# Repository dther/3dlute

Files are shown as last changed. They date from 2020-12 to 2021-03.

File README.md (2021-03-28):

# 3D Lute Project

An attempt at making a cheap and accessible student lute that can be printed on a standard FDM 3D printer,
and be similar enough in tone and playing style to be useful for learning the fundamentals.

Various instruments of the Renaissance-Baroque lute family will hopefully become available.
Currently, only one instrument is being worked on.

## Current Instruments

 - Lutekulele *WIP* - A lute-shaped ukelele, strung in doubled courses and tuned g-c-e-a,
   with the G course in octaves and all others in unison.
   Tuned like a renaissance guitar, and thus already has a repetoire.
   Primarily a proof-of-concept that this project is at all possible.
   Could charitably be called a "mandore" or "mandolino", and restrung to have a more historical
   tuning of g-f-g-f or g-c-g-c.

## Planned instruments

 - Medieval Lute - An early medieval lute, 4 strings in double courses.
 - 6c Tenor Renaissance Lute - The goal of this project.
 - 12c Baroque Lute - Hopefully. I doubt this kind of thing is possible.

## LICENSE

(c) Rudy Dellomas III,
See github profile or <https://dther.xyz> for contact details

Published under [CC BY-SA-NC][#license].

This is primarily to prevent unscrupulous parties from printing and selling these
in large print farms. Please send me an email if you'd like to negotiate commercial usage,
or have produced a creative derivative and would like to relicense.

[#license]:https://creativecommons.org/licenses/by-nc-sa/4.0/

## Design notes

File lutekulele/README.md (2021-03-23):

# Lutekulele

WARNING: this is currently *Heavily in progress.*
I don't have a solid method of generating and tweaking stl files yet,
it's a lot of eyeballing and prayer right now.
Make at your own risk.

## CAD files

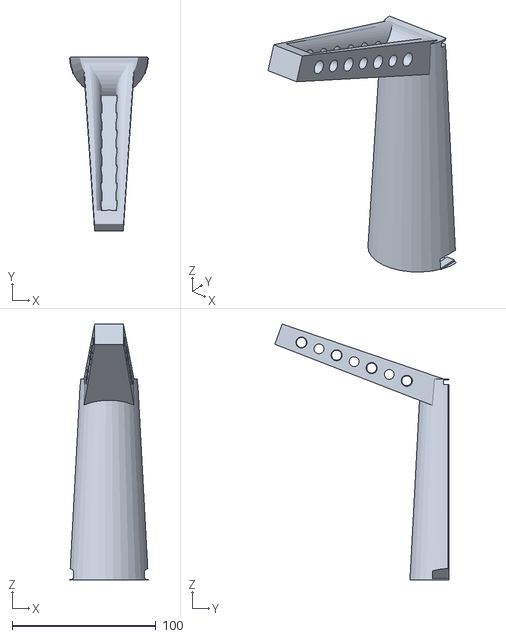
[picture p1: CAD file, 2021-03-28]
lutekulele/neck.stl
54.8 x 121.3 x 178.1

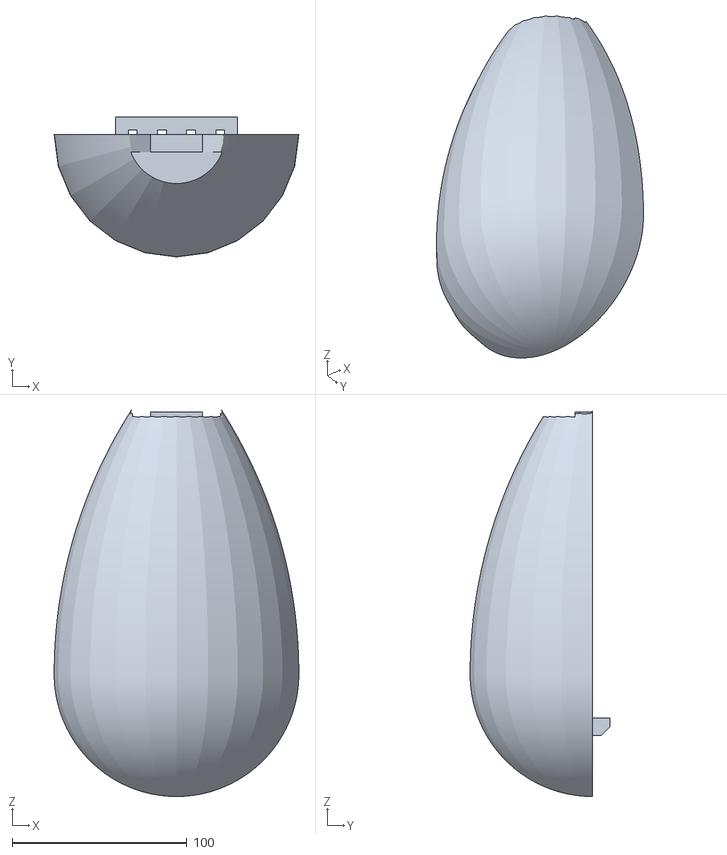
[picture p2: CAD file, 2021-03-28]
lutekulele/body.stl
140.0 x 80.0 x 220.8

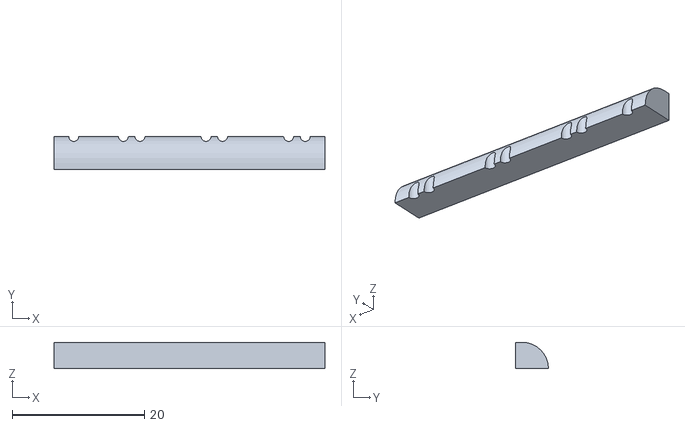
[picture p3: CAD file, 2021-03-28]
lutekulele/nut.stl
41.0 x 5.00 x 4.00

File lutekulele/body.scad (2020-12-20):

include <src/BOSL/shapes.scad>
include <src/BOSL/transforms.scad>
use <src/BOSL/constants.scad>
use <neck.scad>

//set to 0 so as to make hole bigger
neck_block_tolerance=0;

module luteshape(radius) {
    translate([0,radius,0]) union() {
        circle(radius);
        difference() {
            intersection() {
                translate([radius,0,0]) circle(2*radius);
                translate([-radius,0,0]) circle(2*radius);
            }
            translate([0,-radius,0]) square(radius*2, center=true);
        }
    }
}

module luteshape2(radius) {
    translate([0,radius,0]) union() {
        circle(radius);
        
        difference() {
        
            intersection() {
            
                translate([3*radius,0,0]) circle(4*radius);
                translate([-3*radius,0,0]) circle(4*radius);
            }
            translate([0,-2*radius,0]) square(radius*4, center=true);
        }
    }
}

module lutebody(radius) {
    rotate_extrude(angle=180, $fn=24) difference() {
        luteshape2(radius, $fn=360);
        square(radius*100);
    }
}

module roughneck() {
// used for visualisation purposes but also for
// cutting the slot in the neck block
    translate([0, 0, 210]) union() {
        //NUT
        translate([0,-4,140]) nut();
        difference() {
            neckbody(neck_block_tolerance=neck_block_tolerance);
            translate([0,-4,140]) nut_cut();
        }
        difference() {
            cyl(l=10, d1=56, d2=56, align=ALIGN_POS, $fn=360);
            // translate to account for fang inlay
            translate([0,-10,0]) cuboid(size=[100,100,20], align=V_BACK+V_UP);
            
        }
    }
}

module soundbar(l=65,thickness=3,height=10) {
    difference() {
        cuboid(size=[l, height, thickness], align=V_FRONT+V_UP+V_DOWN);
        //scallop
        translate([l/2,1,0]) cyl(d=height*4,h=thickness+2, align=V_FRONT+V_UP+V_DOWN);
        mirror([1,0,0]) translate([l/2,1,0]) cyl(d=height*4,h=thickness+2, align=V_FRONT+V_UP+V_DOWN);
    }
}

module bridge(length=70, course_width=5, string_height=5, bridge_height=10) {
    difference() {
        cuboid(size=[length,bridge_height,10], align=V_BACK+V_DOWN, chamfer=5,
                edges=EDGE_BOT_BK);
        //slots for strings
        hole_height=(bridge_height-string_height)/2; //hole height =/= string height
        //TODO: Feels a bit short now. Going to need to do some testing.
        xspread(l=50,n=4) cuboid(size=[course_width,hole_height,25], align=V_BACK);
    }
}

difference() {
    union() {
        lutebody(70);
    }
    translate([0,-2,10]) difference() {
        lutebody(65);
        //neck block
        translate([0,0,195]) cuboid(size=[70,70,50], align=ALIGN_POS);
    }
    //Hole?
    translate([0,0,130])cyl(d=50, h=20, orient=ORIENT_Y);
    //View soundboard
    //translate([0,-70, 0]) cuboid(size=[200,100,300], align=ALIGN_POS);
    // Neck slot
    translate([0,0.001,0]) #roughneck();
    //TODO: add some kind of "flare" to the back that can be filled with filament-solder
    //TODO: at the same time, increses the tolerance a bit. It's too tight to press fit right now.
}

//roughneck();
//Bridge
// 50-5 to account for nut
translate([0,0,45]) bridge();
// Barring?
// TODO: INCREDIBLY HACKY AND GROSS PLEASE FIX
bar_dist=10;
translate([0,-2,200-bar_dist*1]) soundbar(l=90);
translate([0,-2,200-bar_dist*3]) soundbar(l=110);
translate([0,-2,200-bar_dist*5]) soundbar(l=125);
translate([0,-2,200-bar_dist*6]) soundbar(l=130);
translate([0,-2,200-bar_dist*7]) soundbar(l=135);
translate([0,-2,200-bar_dist*8]) soundbar(l=140);
translate([0,-2,200-bar_dist*9]) soundbar(l=145);
translate([0,-2,200-bar_dist*11.5]) soundbar(l=150);
translate([0,-2,200-bar_dist*14]) soundbar(l=145);
//Treble and bass bars
translate([-30,-2, 200-bar_dist*16.5]) rotate([0,-20,0]) cuboid($fn=10, size=[30,5,3],align=V_FRONT+V_UP+V_DOWN, fillet=2.5, edges=EDGE_FR_RT+EDGE_FR_LF);
translate([-15,-2,200-bar_dist*17.5]) rotate([0,-60,0]) cuboid($fn=10, size=[25,5,3],align=V_FRONT+V_UP+V_DOWN, fillet=2.5, edges=EDGE_FR_RT+EDGE_FR_LF);
union() {
    translate([20,-2,200-bar_dist*17.5])cuboid(size=[30,5,3], $fn=10, edges=EDGE_FR_LF, fillet=2.5, align=V_FRONT+V_UP+V_DOWN);
    translate([41,-2,(200-bar_dist*17)+1.45])
            rotate([0,-45,0]) cuboid(size=[20,5,3], $fn=10, edges=EDGE_FR_RT, fillet=2.5, align=V_FRONT+V_UP+V_DOWN);
}
/*
translate([0,0,10]) difference() {
cylinder(h=370, d=35, $fn=100);
translate([-40, 0,0]) cube([100,100,1000]);
}*/

//luteshape2(10);

//scale length visualiser
//translate([0,0,45]) cyl(l=300, d=10, align=ALIGN_POS);
//
//String layout visualiser
//translate([0,0,45]) prismoid(size1=[55,5],size2=[37,5],h=300);

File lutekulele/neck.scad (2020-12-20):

include <src/BOSL/constants.scad>
use <src/BOSL/shapes.scad>
use <src/BOSL/masks.scad>

//Added to the fang inlay thingy to increase clearances between it and the neck block slot.
//SET TO 0 BEFORE PRINTING THE BODY!!!
neck_block_tolerance=1.5;

module neckbody(length=140, bottom_diameter=55, top_diameter=40, neck_block_tolerance=neck_block_tolerance) {
    union() {
    difference() {
        cyl(l=length, d1=bottom_diameter,d2=top_diameter, align=ALIGN_POS);
        //cut entire thing in half
        translate([-bottom_diameter/2, 0, -5]) cube([bottom_diameter+10,bottom_diameter+10,length+10]);
        // the fangs inlay thing
        translate([-15,0,0]) right_triangle(size=[15,10+neck_block_tolerance,10], orient=ORIENT_Y, align=V_FRONT+V_UP+V_LEFT);
        mirror([1,0,0]) translate([-15,0,0]) right_triangle(size=[15,10+neck_block_tolerance,10], orient=ORIENT_Y, align=V_FRONT+V_UP+V_LEFT);
        cuboid(size=[30+neck_block_tolerance,10+neck_block_tolerance,10+neck_block_tolerance], align=V_FRONT+V_UP);
        // pegbox slot
        translate([0,-6,130])rotate([70,0,0])difference() {
            prismoid(size1=[35,20], size2=[20,15], h=120);
            //need to truncate it a lil, it's cutting into the nut hole
            cuboid([35,20,10]);
            //TODO: mess with this if you ever plan on printing pegbox separately
        }
        //TODO: add bevel to allow easier fret tying
        // Need to do some trig to figure out the angle...
        // bevel mask is rotated because of neck taper
        bevel_rotation=-(90-atan(length/((bottom_diameter-top_diameter)/2)));
        chamfer_size=1;
        translate([bottom_diameter/2,0,0]) rotate([0,bevel_rotation,0]) chamfer_mask(l=length,chamfer=chamfer_size,align=ALIGN_POS);
        mirror([1,0,0]) translate([bottom_diameter/2,0,0]) rotate([0,bevel_rotation,0]) chamfer_mask(l=length,chamfer=chamfer_size,align=ALIGN_POS);
    }
    //maybe move this?
    translate([0,-6,130])rotate([70,0,0]) pegbox();
    }
}

module pegbox($fn=40) {
    difference() { //comment/uncomment to toggle peg visibility
        union() {
            difference() {
                prismoid(size1=[35,20], size2=[20,15], h=120);
                translate([-5,-10,0])cube([10,50,110]);
                //TODO: ???? agh!
                //translate([0,0,0]) rotate([180,180,0]) right_triangle([20,20,30], orient=ORIENT_X, align=ALIGN_POS);
                //add a fillet here to prevent string cuttin'
                //I have absolutely NO IDEA how this filleting mask works.
                //If you do, please send a pull request on how i can parameterise it better.
                translate([5,10,0]) fillet_mask_z(l=110,r=10,align=ALIGN_POS);
                mirror([1,0,0]) translate([5,10,0]) fillet_mask_z(l=110,r=10,align=ALIGN_POS);
            }
            //TODO: there's probably some kind of trigonometric way to figure out the pie slice angle.
            translate([0, -10, 1])pie_slice(ang=88, l=30, r=20, orient=ORIENT_X, center=true);
        }
        //TODO: turn this into a for loop
        translate([0,0,25]) rotate([0,-90,0]) peg(hole=19);
        translate([0,0,38]) rotate([0,90,0]) peg(hole=19);
        translate([0,0,51]) rotate([0,-90,0]) peg(hole=20);
        translate([0,0,64]) rotate([0,90,0]) peg(hole=20);
        translate([0,0,77]) rotate([0,-90,0]) peg(hole=21);
        translate([0,0,90]) rotate([0,90,0]) peg(hole=21);
        translate([0,0,103]) rotate([0,-90,0]) peg(hole=22);
    } //comment/uncomment this too
}

//d is the initial diameter and decreases
module taper(d=8) {
    //hmm. find some way of calculating this out...
    //cyl(l=30, d1=8, d2=7);
    cyl(l=45, d1=8, d2=6.8);
}

module peg(peg_d=8, head_d=15, join_d=10, peg_l=45, join_l=2, hole=25, hole_d=2) {
    // calculate 1:30 taper
    peg_d2 = peg_d-(peg_l/30);
    difference() {
        union() {
            cyl(l=peg_l, d1=peg_d, d2=peg_d2);
            //translate([0,0,-(peg_l/2+head_d/2)]) cyl(l=peg_d, d=head_d, orient=ORIENT_Y);
            //These should print better...
            //TOO SHARP TOO SHARP OW I HAVE LIKE 3 CUTS
            translate([0,0,-(peg_l/2+head_d/2)]) cuboid(size=[head_d,peg_d,head_d], fillet=head_d/7,
                    $fn=50);
            translate([0,0,-(peg_l/2)]) cyl(l=join_l, d=join_d);
        }
        translate([0,0,-(peg_l/2)+hole]) cyl(l=peg_d*2, d=hole_d, orient=ORIENT_Y, $fn=40);
    }
}

module nut(length=41) {
    difference() {
        cuboid(size=[length,5,4], align=V_BOTTOM+V_BACK);
        translate([0,1,4]) fillet_mask_x($fn=30, l=length,r=4, align=V_BOTTOM+V_BACK);
        //string holes
        between_courses=10;
        between_strings=2.5;
        string_width=1.5;
        //G
        translate([(length/2-3),5,0])#cyl(d=string_width,h=10,$fn=20);
        translate([(length/2-3)-between_strings,5,0])#cyl(d=string_width,h=10,$fn=20);
        //c
        translate([(length/2-3)-(between_strings+between_courses),5,0])#cyl(d=string_width,h=10,$fn=20);
        translate([(length/2-3)-(between_strings+between_courses)-between_strings,5,0])#cyl(d=string_width,h=10,$fn=20);
        //e
        translate([(length/2-3)-2*(between_strings+between_courses),5,0])#cyl(d=string_width,h=10,$fn=20);
        translate([(length/2-3)-2*(between_strings+between_courses)-between_strings,5,0])#cyl(d=string_width,h=10,$fn=20);
        //a
        translate([(length/2-3)-3*(between_strings+between_courses)+between_strings,5,0])#cyl(d=string_width,h=10,$fn=20);
    }
}

module nut_cut(length=41) {
    union() {
        cuboid(size=[length,5,4], align=V_BOTTOM+V_BACK);
        translate([0,1,4]) fillet_mask_x($fn=30, l=length,r=4, align=V_BOTTOM+V_BACK);
    }
}


//The whole neck, with supports

/*
difference(){
union(){
difference() {
    neckbody();
    //translate([0,0,30]) #cuboid(size=[200,150,200],align=V_FRONT+V_UP);//uncomment to print a "test piece" to test if it fits in the neck block slot
}
//fang thingy supports
translate([23,0,0]) cuboid(size=[5,10+neck_block_tolerance,1], align=V_FRONT+V_TOP);
mirror([1,0,0])translate([23,0,0]) cuboid(size=[5,10+neck_block_tolerance,1], align=V_FRONT+V_TOP);
}
difference() {
translate([0,-4,140]) nut_cut();
// nut cut support
translate([0,-4,140]) cuboid(size=[40,10,1],align=V_BOTTOM+V_BACK);
}
}
*/


//translate([0,-4,140]) nut();
//just the N U T
//nut();

// the pegs
        translate([0,0,0]) peg(hole=19);
        translate([20,0,0])peg(hole=19);
        translate([40,0,0]) peg(hole=20);
        translate([0,20,0])peg(hole=20);
        translate([20,20,0]) peg(hole=21);
        translate([40,20,0])peg(hole=21);
        translate([60,20,0])peg(hole=22);

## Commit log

2020-12-09 Initial commit. Barebones README and a hot mess.
    [body.scad, neck.scad]
2020-12-12 Finished neck prototype. Printing it now.
    [body.scad, neck.scad]
2020-12-12 Forgot supports... going to need to reprint.
    [neck.scad]
2020-12-12 Added reworked lute plans. NECK IS TOO NARROW.
    [neck.scad]
2020-12-13 Fixed neck being too narrow.
    [neck.scad]
2020-12-13 Finished prototype bridge! Printing now!
    [body.scad]
2020-12-14 Changed bridge string hole heights
    [body.scad]
2020-12-14 explanatory comment
    [neck.scad]
2020-12-16 Added ways of increasing neck block tolerance
    [body.scad, neck.scad]
2020-12-17 Made pegs easier to print and commands to render
    [neck.scad]
2020-12-17 Designed nut. First printable prototype complete!
    Some notes:
    - Bridge seems too low. first fret buzzes on G and A
    - Try rounding fingerboard edges to allow frets to go around tighter
    - pegs stick. Might need compound?
    - Peg heads are *sharp!* I've broken skin with them. Going to need to
    bevel them.
    [neck.scad]
2020-12-20 Made body.scad always use 0 tolerance neck
    [body.scad, neck.scad]
2020-12-20 Turned flare into straight cylinder
    [body.scad]
2020-12-20 Removed # visualisers + added bevel to neck
    [neck.scad]
2020-12-20 Going to try rounding off the pegs again. Ow...
    [neck.scad]
2021-03-28 Tentative prototype stls
    [body.stl, neck.stl, nut.stl]
